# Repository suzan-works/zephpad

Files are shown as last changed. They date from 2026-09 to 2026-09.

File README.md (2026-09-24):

# Zephpad（ゼフパッド）

AIツールへの入力や承認操作を簡単にすることを主目的とした、自作の左手用マクロパッドです。定型文の入力や、AIが提案した処理の承認・拒否など、繰り返し行う操作を手元のキーで実行できることを目指しています。

4個のキースイッチとロータリーエンコーダを備え、Seeed Studio XIAOを使用しています。ファームウェアはZephyrで実装する予定です。  

ケースはあくまで試作品です。  

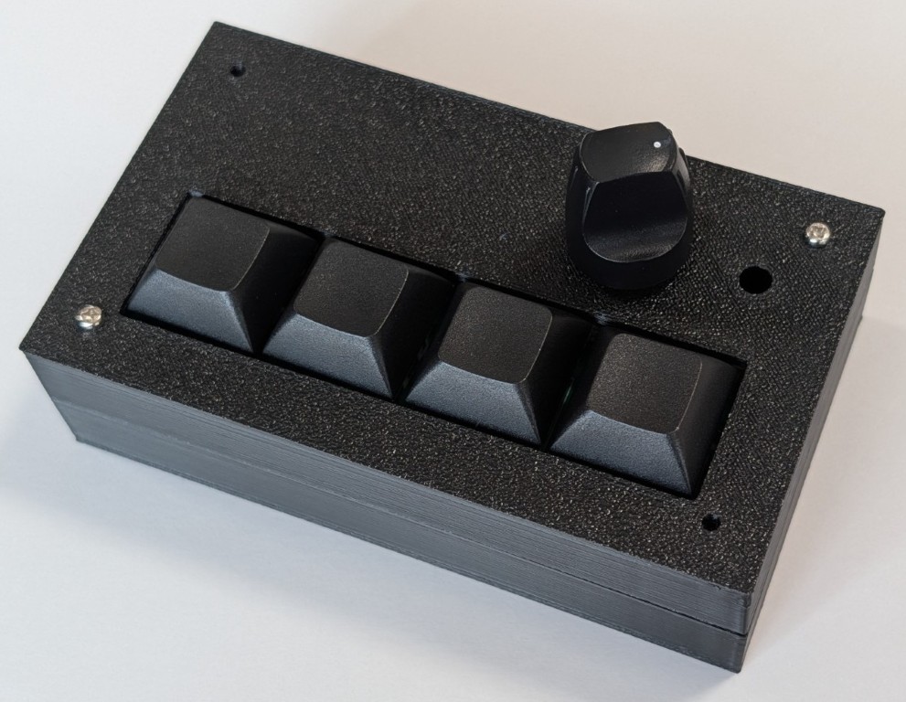
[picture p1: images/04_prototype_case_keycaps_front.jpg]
試作ケース・キーキャップ・ノブを取り付けた外観


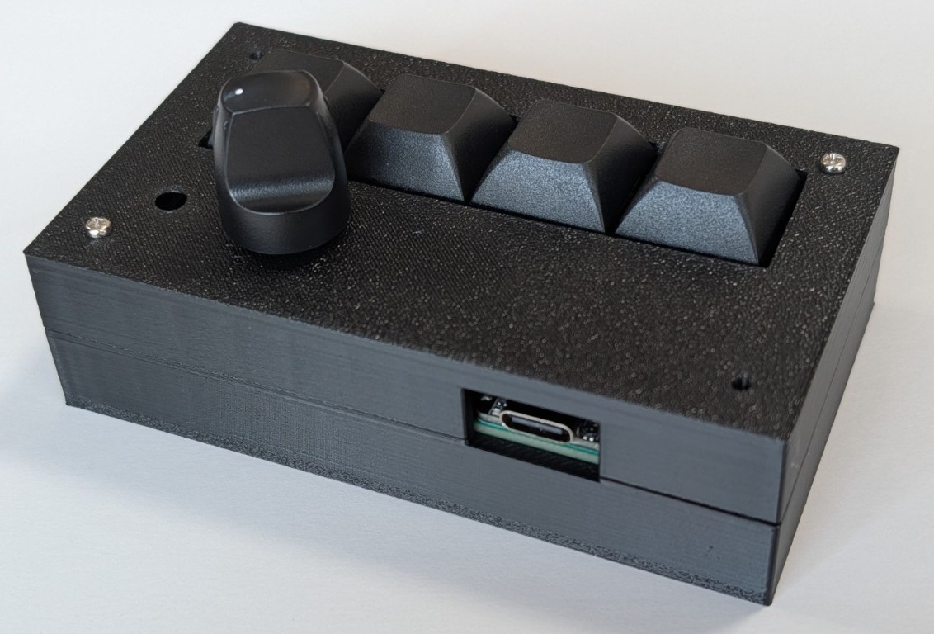
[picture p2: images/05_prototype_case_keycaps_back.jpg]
試作ケースの背面・USB端子側


## 確認できていること

- 4個のキースイッチ入力、ロータリーエンコーダの読み取り、インジケータLEDの点灯。
- XIAO nRF52840で、LiPoバッテリー駆動によるBLEキーボードとしての文字入力。
- ピンヘッダー接続でXIAO nRF52840とXIAO RP2040を差し替え、同じArduinoソースコードを各ボード向けにビルドしてUSBキーボードとして動作。
- バッテリープラス端子のはんだ付け、および試作ケースの組み付け。

(Zephyr版の本格的な実装と、スリープ・ディープスリープによる省電力評価はこれからです。)

## ハードウェア

専用の試作プリント基板に、XIAO、キースイッチ4個、ロータリーエンコーダ、LEDと電流制限抵抗を実装しています。nRF52840を使う構成ではLiPoバッテリーを接続して動作を確認しています。

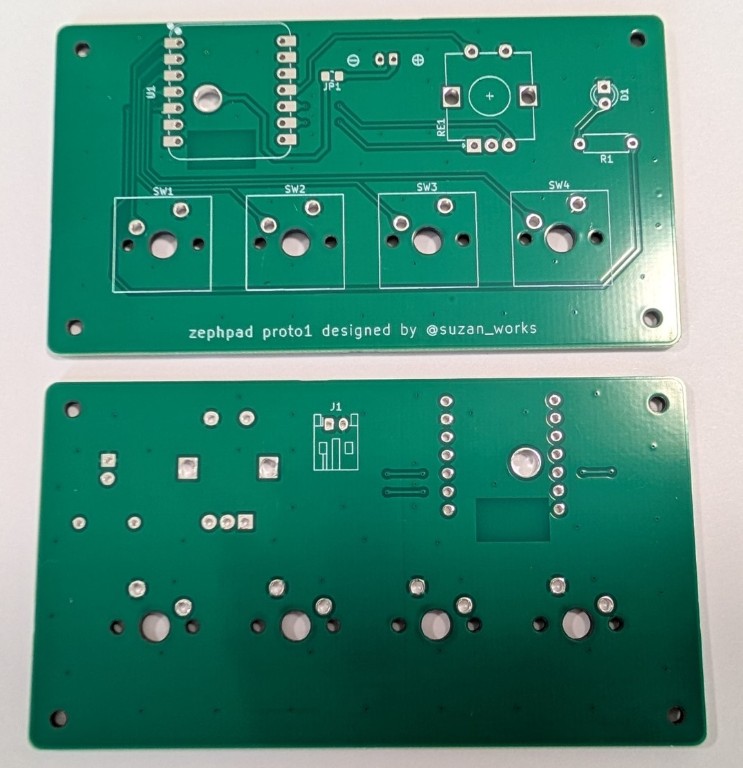
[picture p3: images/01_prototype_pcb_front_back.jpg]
試作プリント基板の表裏


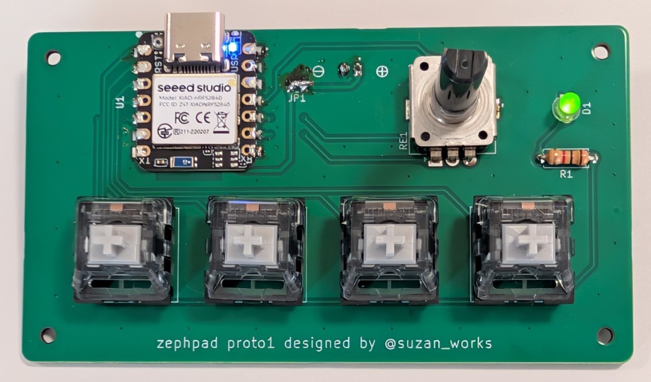
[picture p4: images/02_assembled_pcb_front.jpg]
実装基板の表面


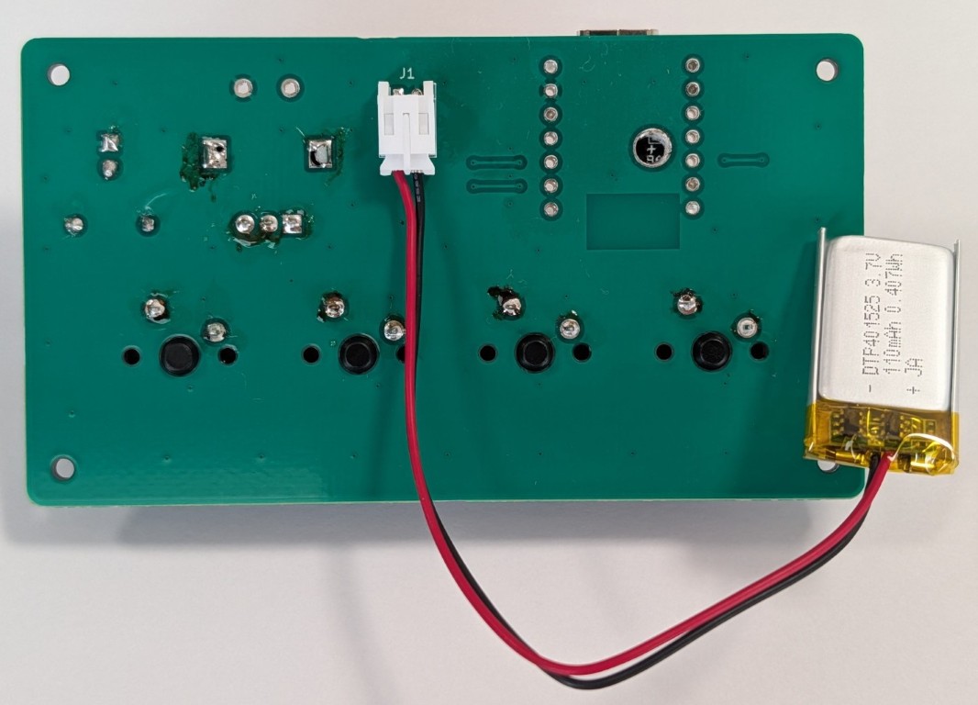
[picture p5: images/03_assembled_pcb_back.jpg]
実装基板の裏面とバッテリー


## 組み立ての概要と注意点

1. 基板に各部品とXIAOをはんだ付けします。
2. nRF52840でバッテリーを使用する場合は、基板裏側の大径スルーホールからXIAO裏面のBAT＋端子を接続します。
3. USBとバッテリーを外した状態で、TP1(BAT＋)とTP2(GND)の短絡がないことを確認します。

ハンダ付けの際に、ピンヘッダーでXiaoを固定すると位置が決めやすいです。(ズレが小さくできる)

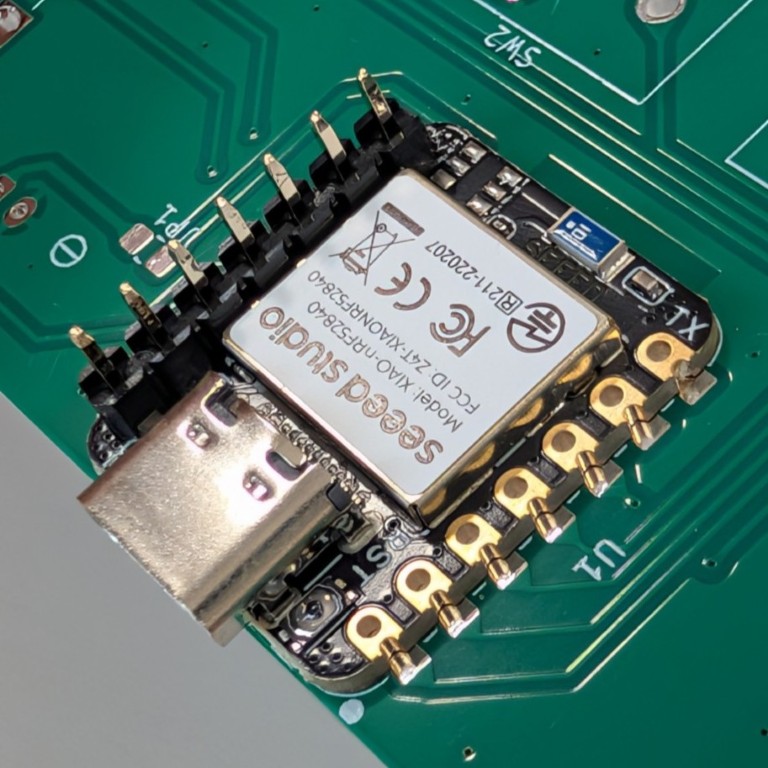
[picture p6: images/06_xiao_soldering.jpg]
XIAOの取り付け・はんだ付け作業


| BAT＋のはんだ付け前 | BAT＋のはんだ付け後 |
| --- | --- |
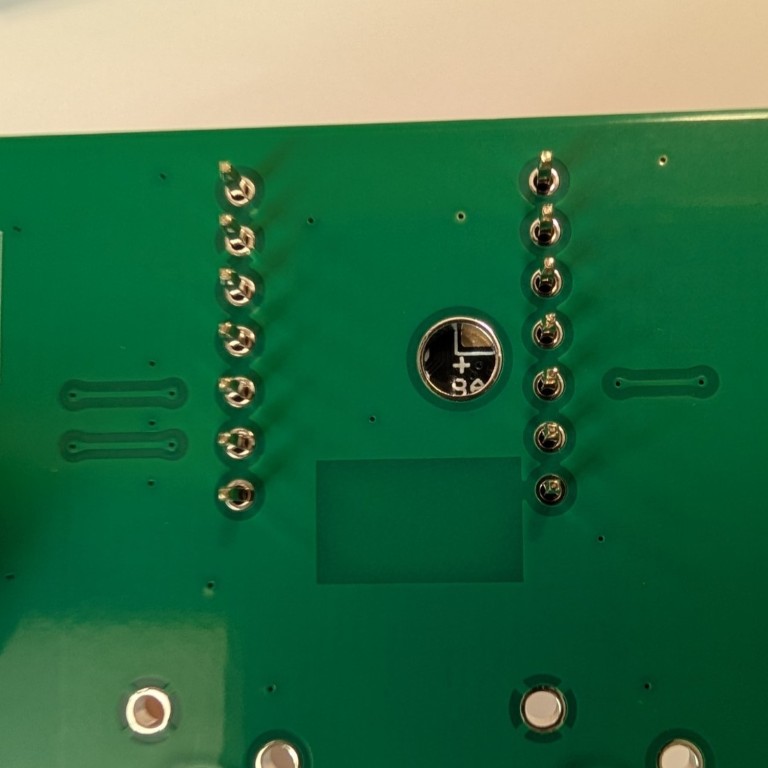
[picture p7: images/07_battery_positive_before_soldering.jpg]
はんだ付け前
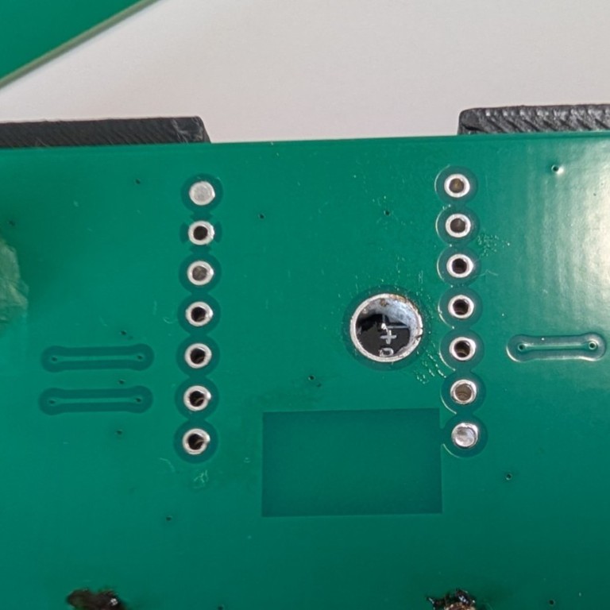
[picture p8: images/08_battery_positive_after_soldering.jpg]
はんだ付け後
|  |  |

### はんだ付け後の短絡チェック

XIAOのはんだ付け後、USBとバッテリーを接続する前に、TP1（VBAT）とTP2（GND）が短絡していないことをテスターで確認します。

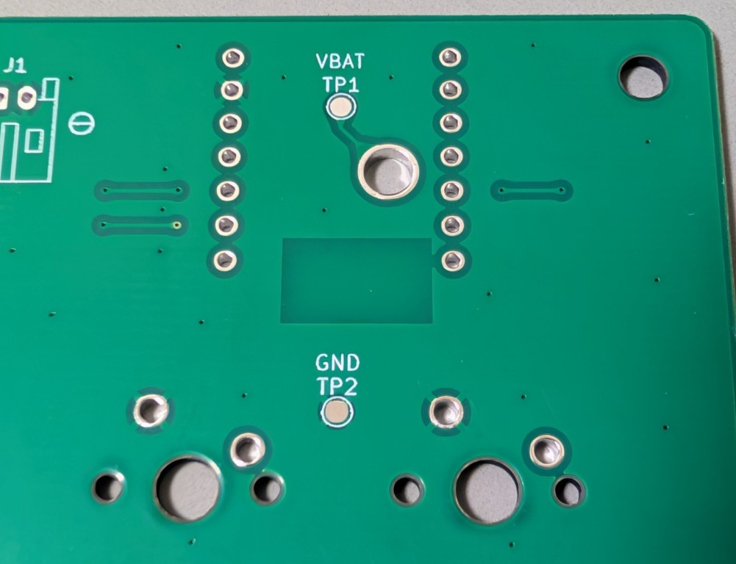
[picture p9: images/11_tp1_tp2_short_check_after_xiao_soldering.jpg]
TP1（VBAT）とTP2（GND）の位置


### XIAOの差し替え

ピンヘッダー接続の試作では、RP2040に差し替えてUSBキーボードとして動作を確認しています。

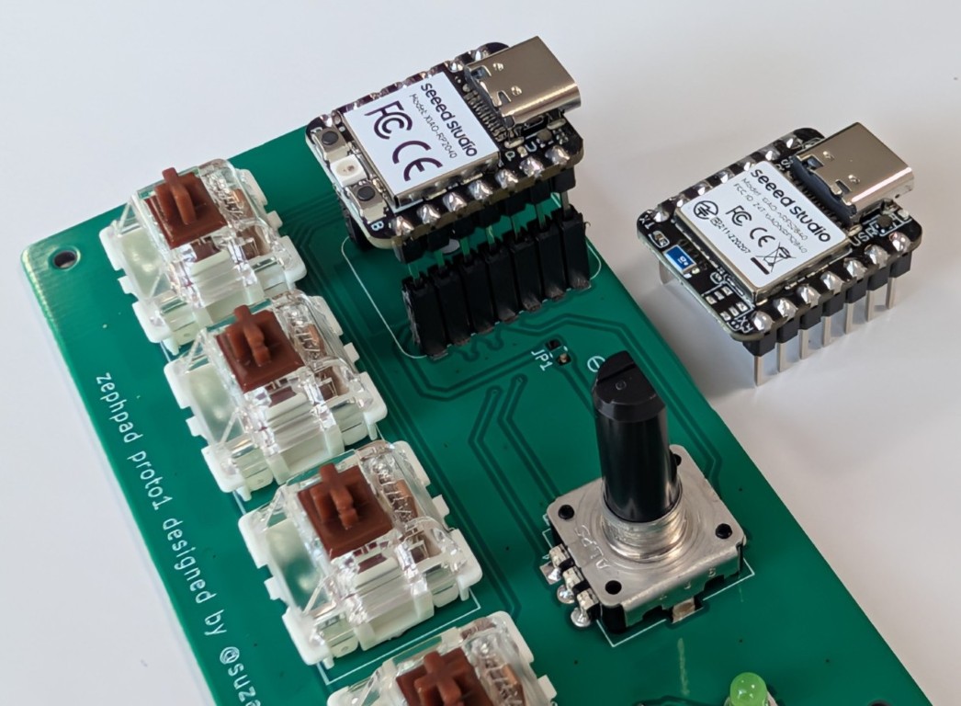
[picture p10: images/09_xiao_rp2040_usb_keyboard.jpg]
XIAO RP2040を取り付けた試作基板


XIAO nRF52840とRP2040では、裏面のバッテリープラス端子を共用できません。Xiao RP2040を付けた場合は、有線USBキーボードのみの動作になります。

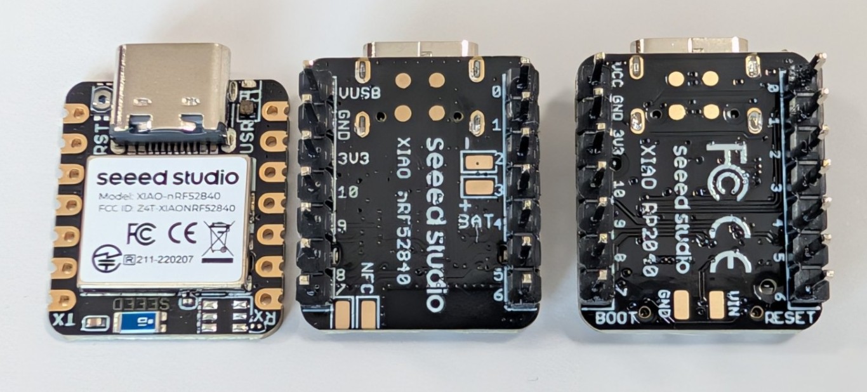
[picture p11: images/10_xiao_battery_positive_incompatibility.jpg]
XIAO nRF52840とRP2040の裏面端子比較


## 設計データ

KiCadプロジェクトは `hardware/kicad/zephpad/zephpad.kicad_pro` に配置します。

KiCanvasで設計データをブラウザから閲覧できます。

- [回路図をブラウザで見る](https://kicanvas.org/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)
- [基板設計ファイルをブラウザで見る](https://kicanvas.org/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)

本資料は開発途中の試作記録です。バッテリー周りの安全性評価と、公開・配布に向けた条件の整理は完了していません。

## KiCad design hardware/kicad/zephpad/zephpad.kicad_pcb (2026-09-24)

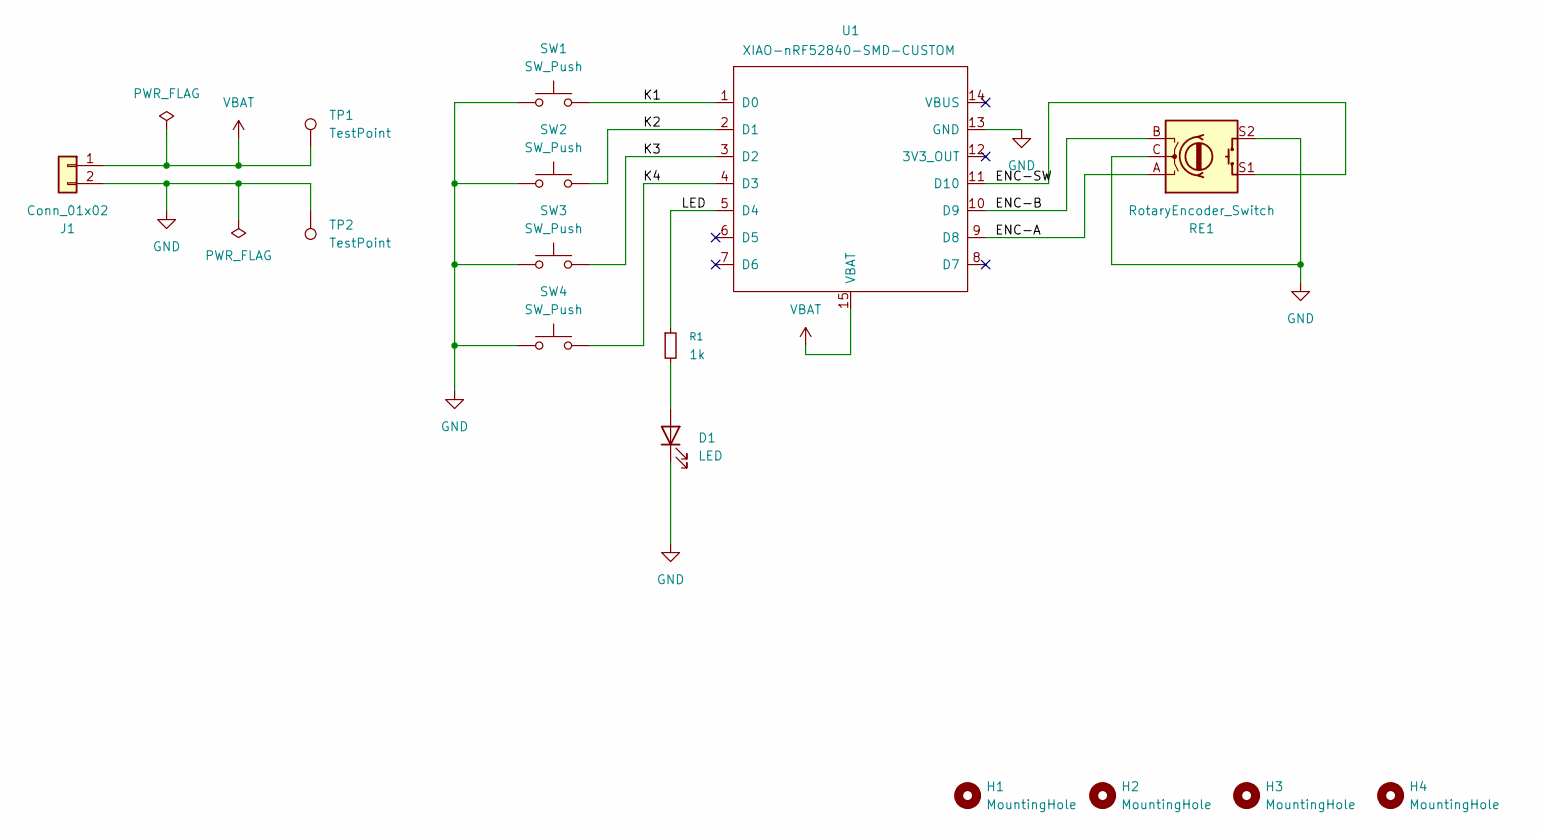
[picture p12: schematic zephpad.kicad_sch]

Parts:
D1: LED; LED_D3.0mm
H1, H2, H3, H4: MountingHole; MountingHole_3.2mm_M3
J1: Conn_01x02; JST_PH_S2B-PH-K_1x02_P2.00mm_Horizontal
R1: 1k; R_Axial_DIN0207_L6.3mm_D2.5mm_P10.16mm_Horizontal
RE1: RotaryEncoder_Switch; RotaryEncoder_Alps_EC12E-Switch_Vertical_H20mm
SW1, SW2, SW3, SW4: SW_Push; SW_Cherry_MX_1.00u_PCB
TP1, TP2: TestPoint; TestPoint_Pad_D1.5mm
U1: XIAO-nRF52840-SMD-CUSTOM; XIAO-nRF52840-DIP-CUSTOM

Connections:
/ENC-A: RE1.A, U1.9 (D8)
/ENC-B: RE1.B, U1.10 (D9)
/ENC-SW: RE1.S1, U1.11 (D10)
/K1: SW1.2, U1.1 (D0)
/K2: SW2.2, U1.2 (D1)
/K3: SW3.2, U1.3 (D2)
/K4: SW4.2, U1.4 (D3)
/LED: R1.1, U1.5 (D4)
GND: D1.1 (K), J1.2, RE1.C, RE1.S2, SW1.1, SW2.1, SW3.1, SW4.1, TP2.1, U1.13 (GND)
unnamed: D1.2 (A), R1.2
VBAT: J1.1, TP1.1, U1.15 (VBAT)

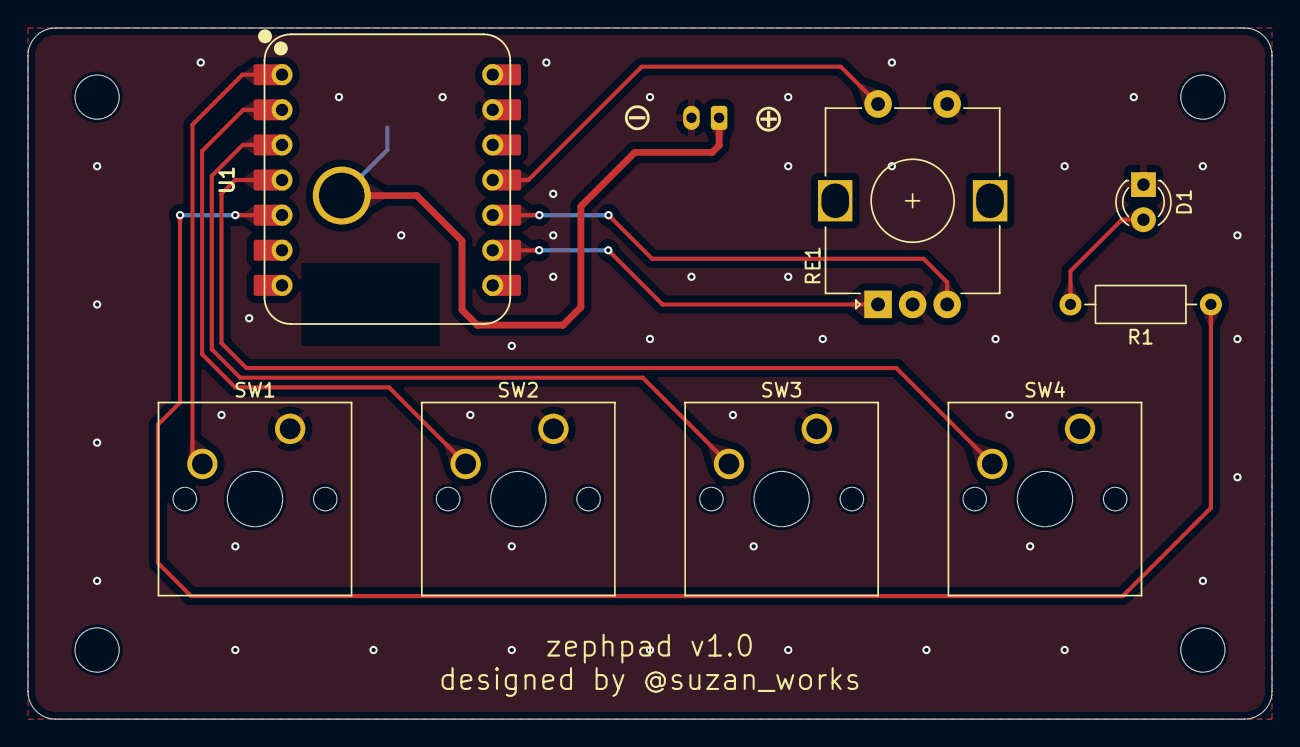
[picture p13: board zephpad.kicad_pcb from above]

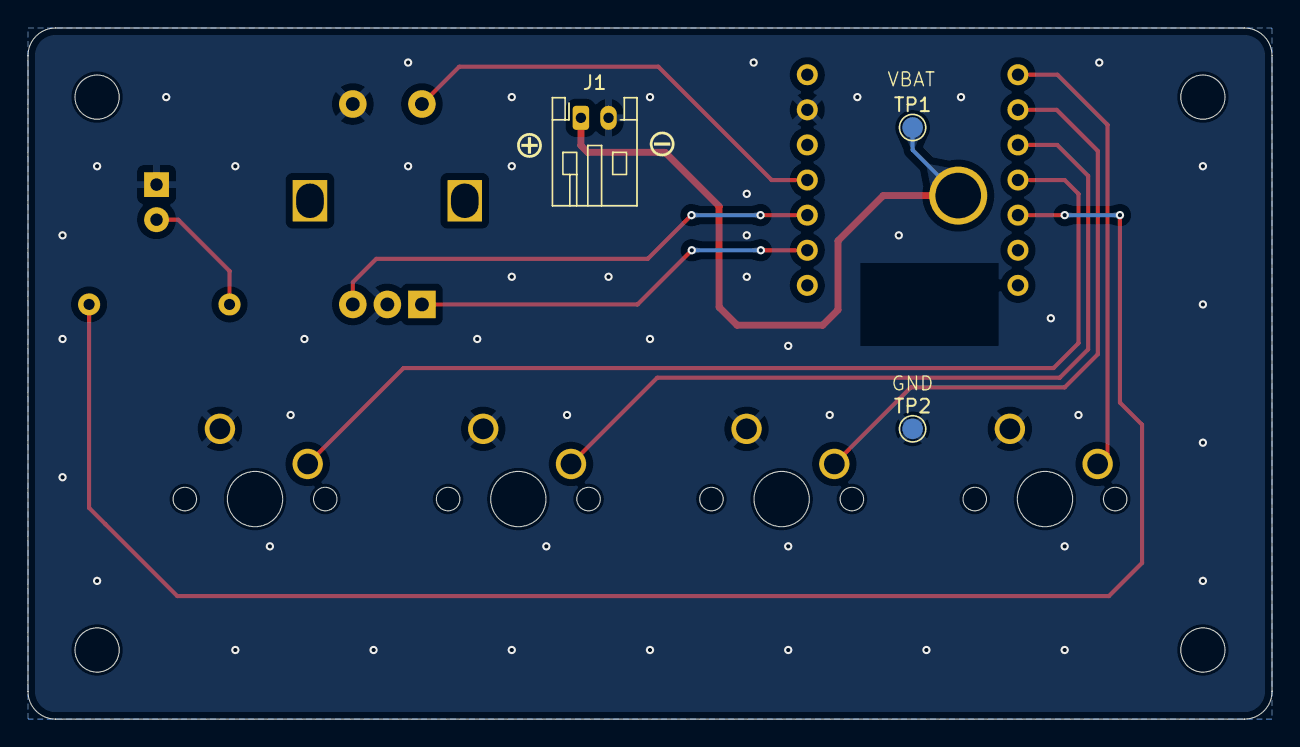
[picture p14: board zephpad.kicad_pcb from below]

Board: 2 copper layers, 90.0 x 50.0 mm, 15 parts (3 on the bottom side), 11 nets.

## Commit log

2026-09-24 KiCadファイルと写真を追加
    [zephpad.kicad_pcb, zephpad.kicad_sch]
2026-09-24 README追記
2026-10-15 Update verified build environment and encoder model
2026-11-03 Update PCB silkscreen for board revision v1.1
